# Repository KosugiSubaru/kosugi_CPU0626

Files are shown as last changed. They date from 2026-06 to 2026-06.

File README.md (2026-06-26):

# kosugi_CPU0626

自作16bit ISA・CPUコアと、対応するCコンパイラ・アセンブラ、周辺HWドライバ一式。

## システム接続関係

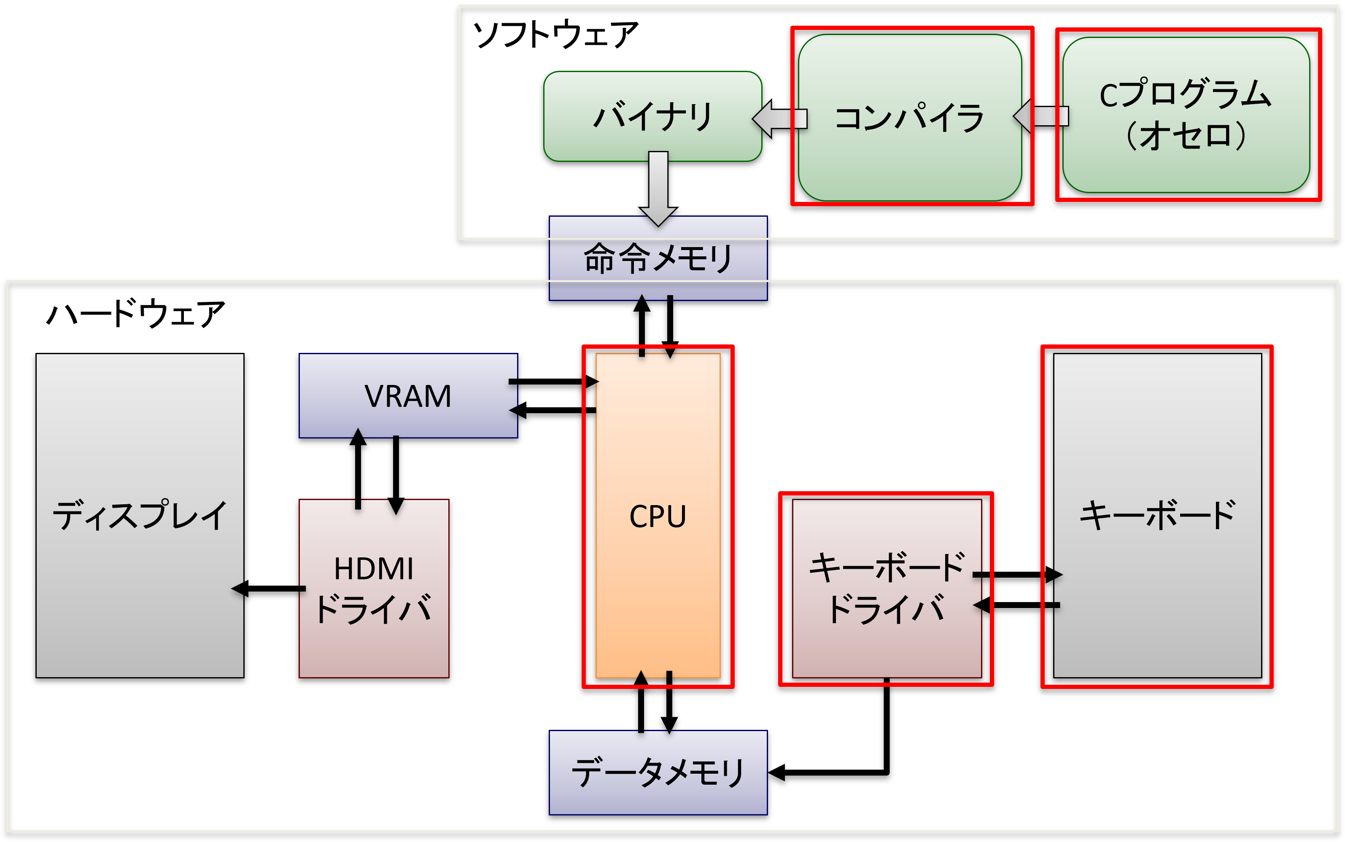
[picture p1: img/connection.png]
システム構成


Cプログラム(オセロ)をコンパイラでバイナリに変換し、命令メモリ経由でCPUに供給する。CPUはデータメモリを介してVRAM・キーボードドライバとやり取りし、HDMIドライバでディスプレイに出力する。赤枠が本リポジトリで自作した部分(コンパイラ、Cプログラム、CPU、キーボードドライバ、キーボード)。

##　CPUスペック

| 項目 | 値 |
|---|---|
| 実体 | TangNano9K (FPGA) に書き込み |
| 動作周波数 | 可変 |
| 命令数 | 16 |
| 命令セット | 手動定義 |
| Verilog回路 | Gemini 3 Flash で自動生成 |
| データ幅 | 16bit |
| レジスタ数 | 16 |
| 命令語長 | 16bit |
| ゼロレジスタ | R0 |

## 構成

- `ISA_definition.yaml` — 命令セット定義(命令一覧・ビットフィールド・フラグ仕様)
- `CPU/` — CPUコア(Verilog RTL)、Verilatorシミュレーション・論理合成スクリプト
- `COMPILER/` — Cコンパイラ(`compiler/`)とアセンブラ(`assembler/`)、テストプログラム(`programs/`)
- `HW_DRIVER/` — HDMI出力・マトリクスキーボード等のFPGA周辺ドライバ(Verilog)
- `KiCad/` — 基板(キーボード)のKiCadプロジェクト

## ISA

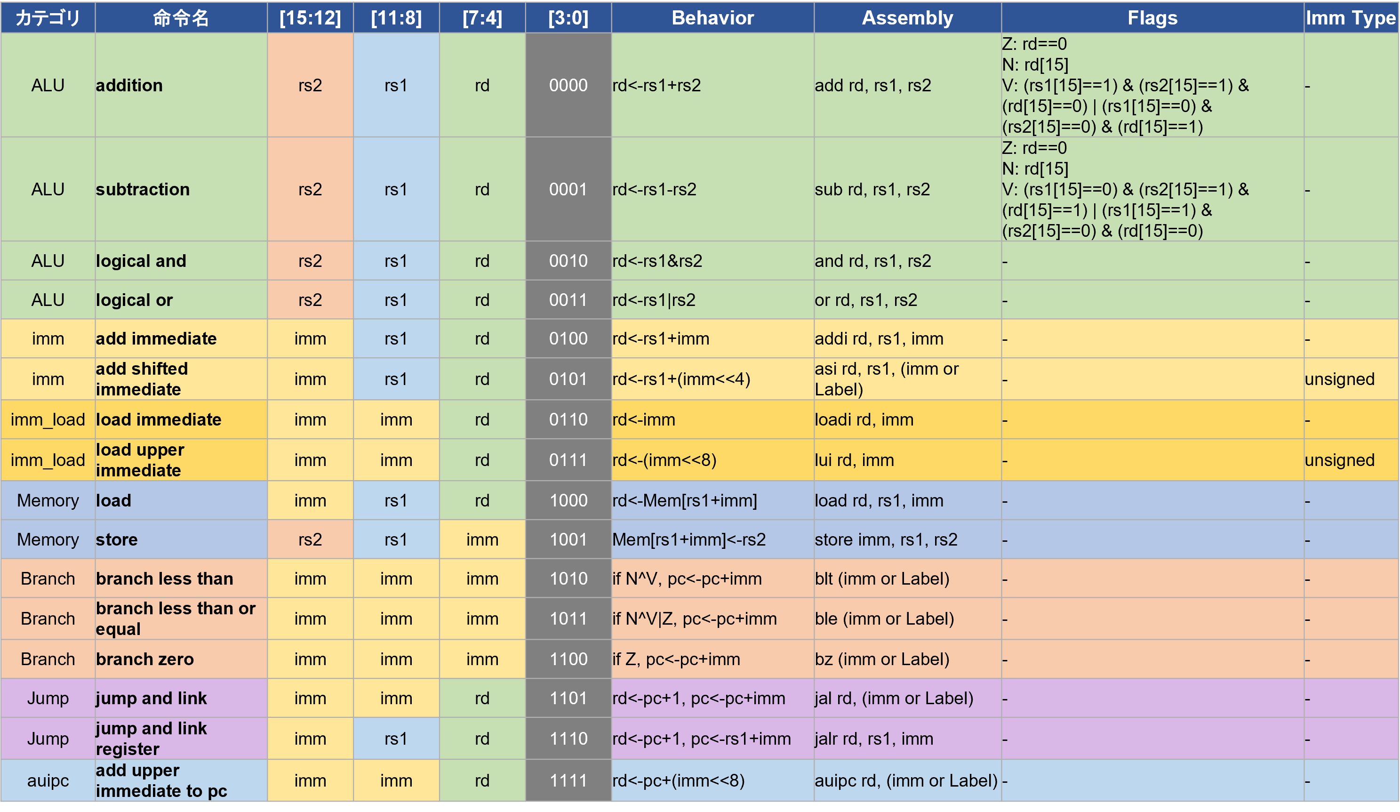
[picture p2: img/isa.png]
命令セット


16bit固定長、ALU系・即値系・メモリアクセス系・分岐/ジャンプ系の命令を定義(詳細は [ISA_definition.yaml](ISA_definition.yaml))。

## データメモリマップ

| アドレス(Decimal) | 内容 |
|---|---|
| 0〜2399 | VRAM |
| 2400〜3429 | Global(グローバル変数) |
| 3430〜4453 | Stack |
| 4454 | Embedded LEDs |
| 4455 | External LEDs |
| 4456～4457 | Keyboard |

データメモリ(0〜)はVRAM・グローバル変数領域・スタックの後ろに、LEDやキーボード入出力用のメモリマップドI/Oを配置している。

## 実装メモ

- Cコンパイラ: [9cc](https://github.com/rui314/9cc) を参考に自作。フロントエンドはLL(1)構文解析、バックエンドはスタックマシン向けコード生成。
- アセンブラ: Claude Codeで作成。長距離ジャンプは `auipc` + `asi` + `addi` に変換してアドレス16bitを充填する。

### 規模感

- Cコンパイラ本体: 約560行(C言語)
  - `stdio.h` などの標準ライブラリはinclude不可。入出力関数は自作(`printf`/`scanf`等は使用不可)
  - 宣言できる型は `int` のみ(すべて16bit確保)。構造体・2次元配列は未対応
- 生成アセンブリ: 約16200行(スタックマシン向け・最適化なしのコンパイラのため冗長だが、ちゃんと動作する)
- 生成バイナリ: 16bit × 16245命令 = 32490byte ≈ 32KB

## シミュレーション

### Cプログラムをコンパイル→アセンブルし、CPUの命令メモリに書き込む

```sh
cd COMPILER
./test.sh
```

`programs/myothello.c` をコンパイル・アセンブルし、`CPU/rtl/memory/imem/machine_code_bin.dat` に機械語を書き込みます。

### CPUをシミュレーション

```sh
cd CPU/script
./build_verilator.sh
```

Verilatorでビルドし、`tb_top_gen.cpp` によるテストベンチを実行します(波形: `tb_top_gen.vcd`)。

### 論理合成・回路図生成

```sh
cd CPU/script
./synthesize.sh
```

`rtl/cpu/` 配下の各モジュールをyosysで論理合成し、netlistsvgで回路図(SVG)を生成します。

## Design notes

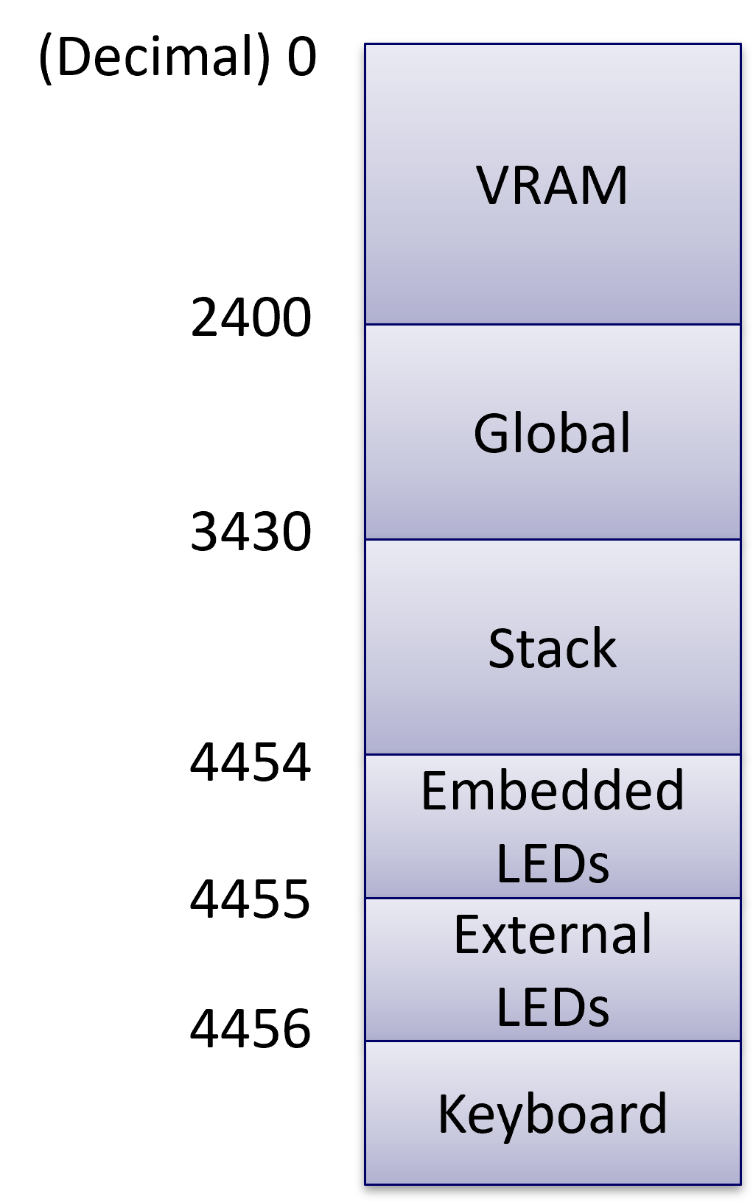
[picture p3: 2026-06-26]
img/dmem.png

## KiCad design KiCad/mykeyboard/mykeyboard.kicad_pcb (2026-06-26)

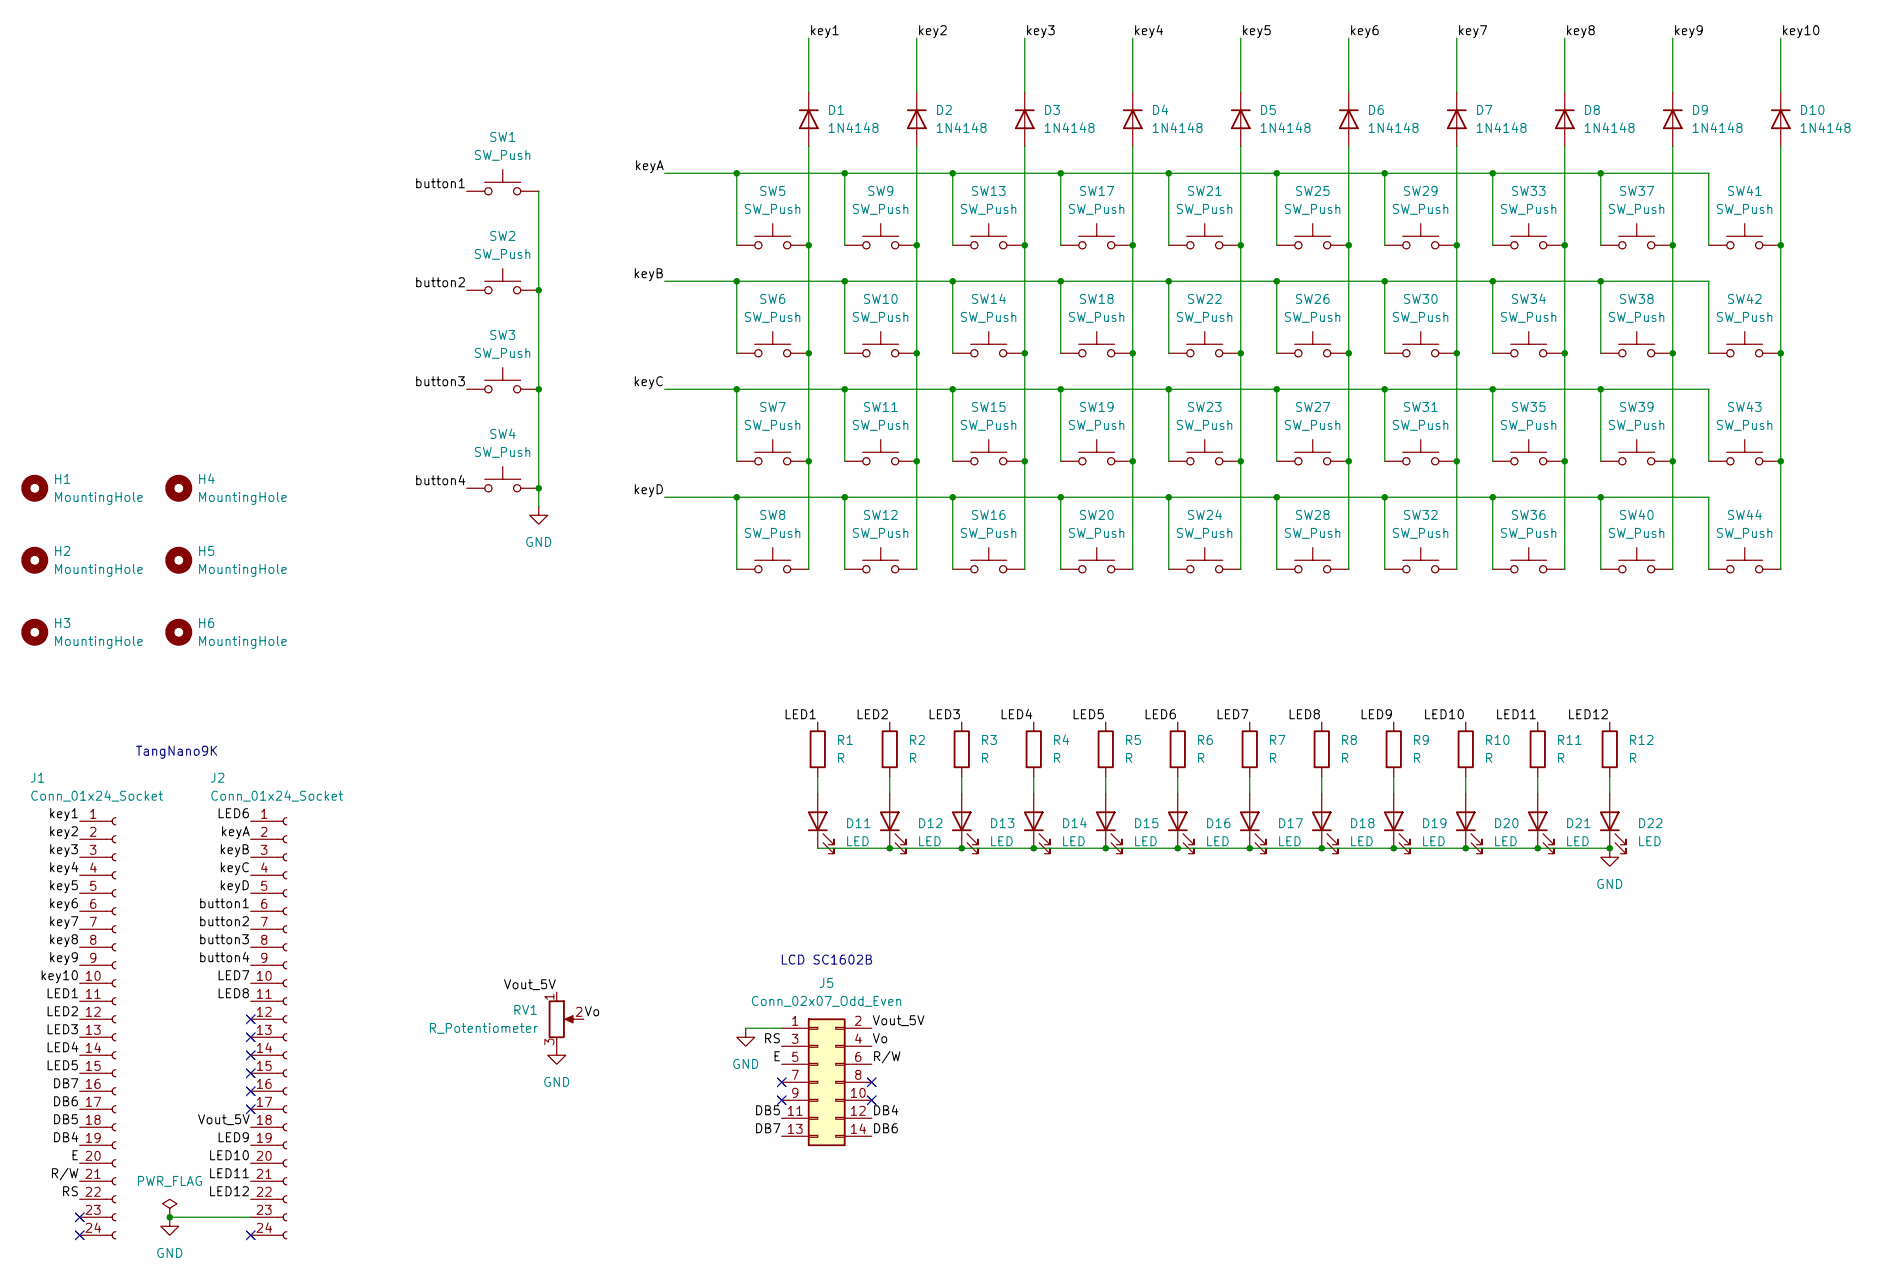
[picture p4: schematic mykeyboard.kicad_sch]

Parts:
D1, D2, D3, D4, D5, D6, D7, D8, D9, D10: 1N4148; D_DO-35_SOD27_P7.62mm_Horizontal
D11, D12, D13, D14, D15, D16, D17, D18, D19, D20, D21, D22: LED; LED_D3.0mm
H1, H2, H3, H4, H5, H6: MountingHole; MountingHole_3.2mm_M3
J1, J2: Conn_01x24_Socket; PinSocket_1x24_P2.54mm_Vertical
J5: Conn_02x07_Odd_Even; PinSocket_2x07_P2.54mm_Vertical
R1, R2, R3, R4, R5, R6, R7, R8, R9, R10, R11, R12: R; R_Axial_DIN0204_L3.6mm_D1.6mm_P7.62mm_Horizontal
RV1: R_Potentiometer; 3362P
SW1, SW2, SW3, SW4, SW5, SW6, SW7, SW8, SW9, SW10, SW11, SW12, SW13, SW14, SW15, SW16, SW17, SW18, SW19, SW20, SW21, SW22, SW23, SW24, SW25, SW26, SW27, SW28, SW29, SW30, SW31, SW32, SW33, SW34, SW35, SW36, SW37, SW38, SW39, SW40, SW41, SW42, SW43, SW44: SW_Push; SW_Cherry_MX_1.00u_PCB

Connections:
/DB4: J1.19, J5.12
/DB5: J1.18, J5.11
/DB6: J1.17, J5.14
/DB7: J1.16, J5.13
/E: J1.20, J5.5
/LED1: J1.11, R1.1
/LED2: J1.12, R2.1
/LED3: J1.13, R3.1
/LED4: J1.14, R4.1
/LED5: J1.15, R5.1
/LED6: J2.1, R6.1
/LED7: J2.10, R7.1
/LED8: J2.11, R8.1
/LED9: J2.19, R9.1
/LED10: J2.20, R10.1
/LED11: J2.21, R11.1
/LED12: J2.22, R12.1
/RS: J1.22, J5.3
/R/W: J1.21, J5.6
/Vo: J5.4, RV1.2
/Vout_5V: J2.18, J5.2, RV1.1
/button1: J2.6, SW1.1
/button2: J2.7, SW2.1
/button3: J2.8, SW3.1
/button4: J2.9, SW4.1
/key1: D1.1 (K), J1.1
/key2: D2.1 (K), J1.2
/key3: D3.1 (K), J1.3
/key4: D4.1 (K), J1.4
/key5: D5.1 (K), J1.5
/key6: D6.1 (K), J1.6
/key7: D7.1 (K), J1.7
/key8: D8.1 (K), J1.8
/key9: D9.1 (K), J1.9
/key10: D10.1 (K), J1.10
/keyA: J2.2, SW5.1, SW9.1, SW13.1, SW17.1, SW21.1, SW25.1, SW29.1, SW33.1, SW37.1, SW41.1
/keyB: J2.3, SW6.1, SW10.1, SW14.1, SW18.1, SW22.1, SW26.1, SW30.1, SW34.1, SW38.1, SW42.1
/keyC: J2.4, SW7.1, SW11.1, SW15.1, SW19.1, SW23.1, SW27.1, SW31.1, SW35.1, SW39.1, SW43.1
/keyD: J2.5, SW8.1, SW12.1, SW16.1, SW20.1, SW24.1, SW28.1, SW32.1, SW36.1, SW40.1, SW44.1
GND: D11.1 (K), D12.1 (K), D13.1 (K), D14.1 (K), D15.1 (K), D16.1 (K), D17.1 (K), D18.1 (K), D19.1 (K), D20.1 (K), D21.1 (K), D22.1 (K), J2.23, J5.1, RV1.3, SW1.2, SW2.2, SW3.2, SW4.2
unnamed: D1.2 (A), SW5.2, SW6.2, SW7.2, SW8.2
unnamed: D2.2 (A), SW9.2, SW10.2, SW11.2, SW12.2
unnamed: D3.2 (A), SW13.2, SW14.2, SW15.2, SW16.2
unnamed: D4.2 (A), SW17.2, SW18.2, SW19.2, SW20.2
unnamed: D5.2 (A), SW21.2, SW22.2, SW23.2, SW24.2
unnamed: D6.2 (A), SW25.2, SW26.2, SW27.2, SW28.2
unnamed: D7.2 (A), SW29.2, SW30.2, SW31.2, SW32.2
unnamed: D8.2 (A), SW33.2, SW34.2, SW35.2, SW36.2
unnamed: D9.2 (A), SW37.2, SW38.2, SW39.2, SW40.2
unnamed: D10.2 (A), SW41.2, SW42.2, SW43.2, SW44.2
unnamed: D11.2 (A), R1.2
unnamed: D12.2 (A), R2.2
unnamed: D13.2 (A), R3.2
unnamed: D14.2 (A), R4.2
unnamed: D15.2 (A), R5.2
unnamed: D16.2 (A), R6.2
unnamed: D17.2 (A), R7.2
unnamed: D18.2 (A), R8.2
unnamed: D19.2 (A), R9.2
unnamed: D20.2 (A), R10.2
unnamed: D21.2 (A), R11.2
unnamed: D22.2 (A), R12.2

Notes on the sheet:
LCD SC1602B
TangNano9K

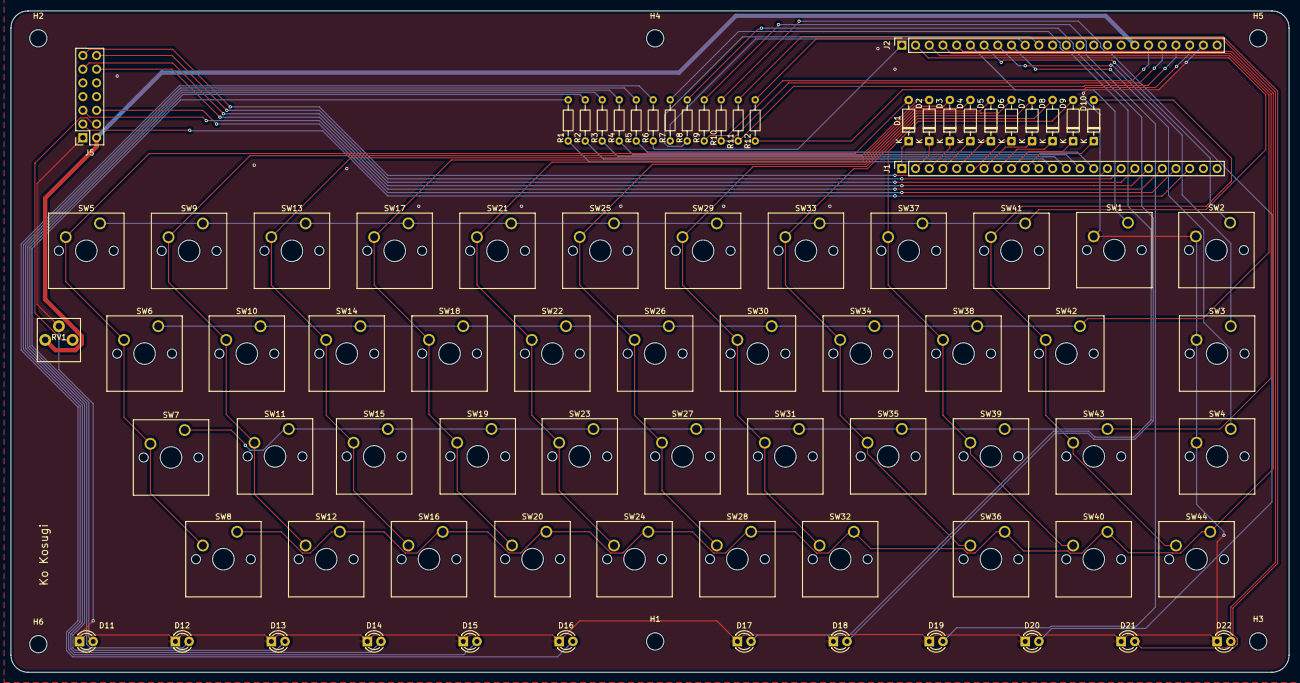
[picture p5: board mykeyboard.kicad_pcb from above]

Board: 2 copper layers, 236.9 x 122.6 mm, 88 parts (0 on the bottom side), 62 nets.

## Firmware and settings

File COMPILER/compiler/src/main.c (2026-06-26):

#include "header.h"

// コンパイラのメイン関数

char *user_input;

int main(int argc, char **argv) {
    if (argc != 2) {
        error("Compile error: Incorrect number of arguments.");
        return 1;
    }

    FILE *input_program = fopen(argv[1], "r");
    int program_size;
    if (input_program == NULL) {
        error("Compile error: Cannot open program file.");
        fclose(input_program);
        return 1;
    }
    fseek(input_program, 0, SEEK_END);  //ファイルポインタをファイルの最後に移動
    program_size = ftell(input_program);//ファイルポインタの現在位置を取得
    rewind(input_program);              //ファイルポインタを先頭に戻す

    user_input = malloc(program_size + 2);//プログラムのサイズ+2バイト分のメモリを確保
    fread(user_input, program_size, 1, input_program);
    user_input[program_size] = '\0';
    fclose(input_program);
  

  // トークナイズする/トークンの連結リストを作成する
    token = tokenize();
    fprintf(stderr, "Successfully tokenized.\n\n");

  //パースする/抽象構文木を作成する
    program();
    fprintf(stderr, "Successfully parsed.\n\n");
    print_function_table();
    print_gvar_list();
    fprintf(stderr, "Global_size: %d\n\n", Gvar_size);
    print_strings();
    print_sizeofcode();

//   抽象構文木を下りながらコード生成
//   printBootStack();
    init();
    // gen_string_ascii();
    for (int i = 0; code[i]; i++) {
        gen(code[i]);
        printf(" # 文が終わるごとにスタックトップをポップ\n");
        printf("  addi r7, r7, -1\n\n");
    }

  //3アドレスコード生成
//   printBootReg();
//   now_quad = calloc(1, sizeof(Quadruple));
//   for (int i = 0; code[i]; i++) {
//     gen_tac(code[i]);
//   }
//   printQuads();

//   //関数ブロック生成
//   gen_FB();
//   printFunc();

//   //基本ブロック生成
//   gen_BB();

//   //生存解析
//   livness_analysis();

//   //アセンブリコード生成
  
//   gen_machinecode();

    return 0;
}

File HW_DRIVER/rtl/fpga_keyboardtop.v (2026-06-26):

module fpga_keyboardtop (
    input  wire r_clk,
    input  wire r_rst,

    input  wire [3:0] r_signal, // Input signal for the matrix key
    input  wire [3:0] r_buttons, // Input buttons

    output wire [5:0]  o_embeddedLEDs,
    output wire [11:0] o_LEDs,
    output wire [9:0]  o_control, // Control signals for the matrix key

    output  wire       tmds_clk_n,
    output  wire       tmds_clk_p,
    output  wire [2:0] tmds_d_n,
    output  wire [2:0] tmds_d_p
    // Add other ports as needed
    );

    wire i_rst;
    wire sys_resetp;

    wire [11:0] vram_rd_addr;   // VRAM読み出しアドレス
    wire [7:0]  vram_rd_data;   // VRAMからのデータ

    wire        w_dmem_wen;
    wire [15:0] w_addr_pc, w_addr_alu;
    wire [15:0] w_instr;
    wire [15:0] w_data_alu, w_data_dmem, w_data_key, w_data_inCPU;
    wire [15:0] w_observed_reg_data; // 観測用のレジスタデータ（R7）
    wire [15:0] w_observed_pc_data;  // 観測用のプログラムカウンタデータ（PC）
    
    reg  [11:0]  r_LEDs;         // Output LEDs
    reg  [5:0]   r_embeddedLEDs; // Embedded LEDs
    reg  [15:0]  r_data_inCPU;

    reg         i_clk = 1'b0;   // Internal clock signal for the CPU
    reg  [31:0] r_counter = 32'h00000000;

    assign i_rst = ~r_rst;
    assign sys_resetp = ~sys_resetn;

    assign w_data_inCPU = r_data_inCPU; // Data input to the CPU
    // assign o_embeddedLEDs = r_embeddedLEDs; // Output embedded LEDs
    // assign o_LEDs = r_LEDs; // Output LEDs

    cpu u_cpu (
        .i_clk            (i_clk           ),
        .i_rst_n          (sys_resetn         ),
        .i_instr          (w_instr         ),
        .i_data_from_dmem (w_data_inCPU),

        .o_addr_to_dmem   (w_addr_alu  ),
        .o_data_to_dmem   (w_data_alu  ),
        .o_addr_to_imem   (w_addr_pc  ),
        .o_dmem_wen       (w_dmem_wen      ),
        .o_observed_reg_data(w_observed_reg_data), // 観測用の出力データは未接続
        .o_observed_pc_data(w_observed_pc_data)  // 観測用のプログラムカウンタデータ（PC）
    );

    Gowin_pROM IMEM(
        .dout(w_instr), //output [15:0] dout
        .clk(i_clk), //input clk
        .oce(1'b1), //input oce
        .ce(1'b1), //input ce
        .reset(sys_resetp), //input reset
        .ad(w_addr_pc[15:0]) //input [15:0] ad
    );

    // dmem DMEM(
    //     .i_clk        (i_clk         ),
    //     .i_rst        (i_rst         ),
    //     .i_wen        (w_dmem_wen    ),
    //     .i_addr       (w_addr_alu    ),
    //     .i_data       (w_data_alu    ),
    //     .o_data       (w_data_dmem   )
    // );

    Gowin_SP DMEM(
        .dout(w_data_dmem), //output [15:0] dout
        .clk(~i_clk), //input clk
        .oce(1'b1), //input oce
        .ce(1'b1), //input ce
        .reset(sys_resetp), //input reset
        .wre(w_dmem_wen), //input wre
        .ad(w_addr_alu[12:0]), //input [12:0] ad
        .din(w_data_alu) //input [15:0] din
    );

    Gowin_SDPB VRAM(
        .dout(vram_rd_data), //output [7:0] dout
        .clka(~i_clk), //input clka
        .cea(w_dmem_wen), //input cea
        .reseta(sys_resetp), //input reseta
        .clkb(clk_p), //input clkb
        .ceb(1'b1), //input ceb
        .resetb(sys_resetp), //input resetb
        .oce(1'b1), //input oce
        .ada(w_addr_alu[12:0]), //input [12:0] ada
        .din(w_data_alu[7:0]), //input [7:0] din
        .adb(vram_rd_addr) //input [11:0] adb
    );

    driver_matrixkeyboard DRIVER_MATRIXKEYBOARD (
        .r_clk           (r_clk         ), // Use r_clk for the matrix key driver
        .r_rst           (sys_resetn     ), // Use system reset for the matrix key driver),
        .i_signal        (r_signal      ), // Assuming r_signal is used to store key data
        .o_control       (o_control     ), // Assuming w_addr_alu is used to control the key state
        .o_detected_key  (w_data_key    )  // Assuming w_data_alu is used to store key data
    );

    Gowin_rPLL u_pll (
        .clkin(r_clk),
        .clkout(clk_p5),
        .lock(pll_lock)
    );

    Gowin_CLKDIV u_div_5 (
        .clkout(clk_p),
        .hclkin(clk_p5),
        .resetn(pll_lock)
    );

    Reset_Sync u_Reset_Sync (
        .resetn(sys_resetn),
        .ext_reset(r_rst & pll_lock),
        .clk(clk_p)
    );

    svo_hdmi svo_hdmi_inst (
        .clk(clk_p),
        .resetn(sys_resetn),

        // video clocks
        .clk_pixel(clk_p),
        .clk_5x_pixel(clk_p5),
        .locked(pll_lock),

        // output signals
        .tmds_clk_n(tmds_clk_n),
        .tmds_clk_p(tmds_clk_p),
        .tmds_d_n(tmds_d_n),
        .tmds_d_p(tmds_d_p),

        // VRAMインターフェース
        .vram_rd_addr(vram_rd_addr), // VRAM読み出しアドレス
        .vram_rd_data(vram_rd_data)  // VRAMから
    );
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
